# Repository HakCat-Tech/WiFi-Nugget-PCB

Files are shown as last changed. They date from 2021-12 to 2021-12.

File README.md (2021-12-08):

# WiFi Nugget PCB
This repository contains the PCB design files for the ESP8266 based WiFi Nugget.

### Change Log + Specs
**Beta-v1.0:**  
This design is a proof of concept for a slimmer, more easily manfacturable design based off surface mount components.   
- 0603 SMD components
- ESP12F based module
- SH1106 OLED Screen
- Minimal PCB art

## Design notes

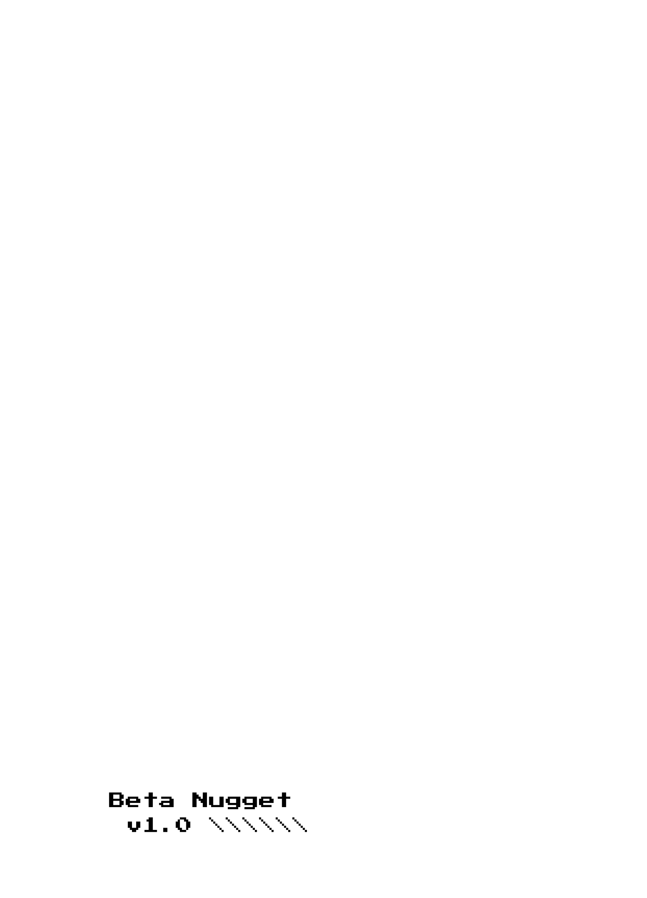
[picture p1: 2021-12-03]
v1.0-Beta-PCB-Art/.svg2shenzhen-cache/images/F.Mask_g1432.png

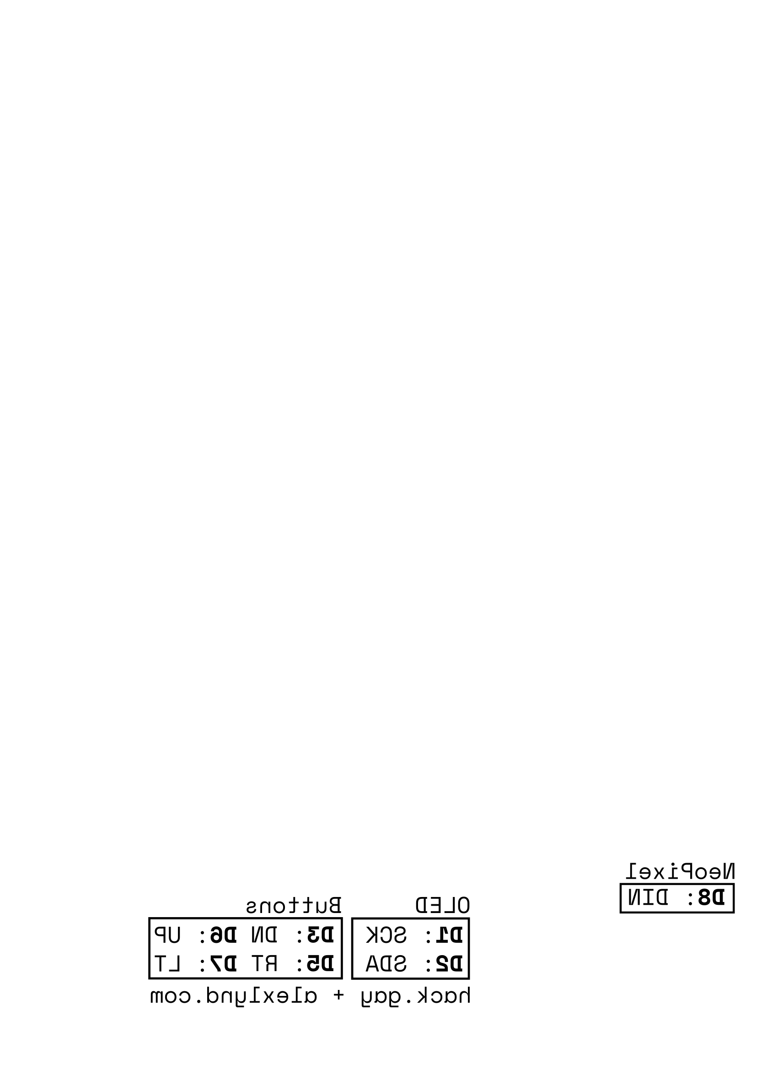
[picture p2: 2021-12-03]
v1.0-Beta-PCB-Art/.svg2shenzhen-cache/images/B.SilkS_g1428.png

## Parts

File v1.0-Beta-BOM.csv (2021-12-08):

Reference | Quantity | Value | Footprint | Datasheet
C4 C8 C10 C11 C12 C13 | 6 | 4.7μF | Capacitor_SMD:C_0603_1608Metric_Pad1.08x0.95mm_HandSolder | ~
C2 | 1 | 4.7 μF | Capacitor_SMD:C_0603_1608Metric_Pad1.08x0.95mm_HandSolder | ~
C1 C3 C5 C6 C7 C14 | 6 | 1 μF | Capacitor_SMD:C_0603_1608Metric_Pad1.08x0.95mm_HandSolder | ~
C9 | 1 | 1μF | Capacitor_SMD:C_0603_1608Metric_Pad1.08x0.95mm_HandSolder | ~
D1 | 1 | SS14 | LED_SMD:LED_0603_1608Metric_Pad1.05x0.95mm_HandSolder | ~
D2 | 1 | RED 0603 | LED_SMD:LED_0603_1608Metric_Pad1.05x0.95mm_HandSolder | ~
D3 | 1 | SS14 | Diode_SMD:D_SOD-123 | ~
D4 | 1 | WS2812B | LED_SMD:LED_WS2812B_PLCC4_5.0x5.0mm_P3.2mm | https://cdn-shop.adafruit.com/datasheets/WS2812B.pdf
J1 | 1 | Micro USB | Connector_USB:USB_Micro-B_Molex-105017-0001 | ~
J2 | 1 | JST PH 2.0 | Connector_JST:JST_PH_S2B-PH-SM4-TB_1x02-1MP_P2.00mm_Horizontal | ~
J3 | 1 | NeoPixel Breakout | Connector_JST:JST_SH_SM03B-SRSS-TB_1x03-1MP_P1.00mm_Horizontal | ~
Q1 | 1 | UMH3N | Package_TO_SOT_SMD:SOT-363_SC-70-6 | http://rohmfs.rohm.com/en/products/databook/datasheet/discrete/transistor/digital/emh3t2r-e.pdf
Q2 | 1 | DMG3415 | Package_TO_SOT_SMD:SOT-23 | ~
R1 R2 R3 R6 R8 R13 R16 R17 | 8 | 4.7K | Resistor_SMD:R_0603_1608Metric_Pad0.98x0.95mm_HandSolder | ~
R9 R10 R11 R12 R14 R15 | 6 | 10K | Resistor_SMD:R_0603_1608Metric_Pad0.98x0.95mm_HandSolder | ~
R4 | 1 | 560K | Resistor_SMD:R_0603_1608Metric_Pad0.98x0.95mm_HandSolder | ~
R5 | 1 | 100K | Resistor_SMD:R_0603_1608Metric_Pad0.98x0.95mm_HandSolder | ~
R7 | 1 | 27K | Resistor_SMD:R_0603_1608Metric_Pad0.98x0.95mm_HandSolder | ~
SW1 | 1 | SPDT | Button_Switch_SMD:SW_SPDT_PCM12 | https://www.digikey.com/en/products/detail/e-switch/EG1215AA/9559277
SW2 | 1 | UP | Button_Switch_SMD:SW_SPST_FSMSM | https://www.digikey.com/en/products/detail/c-k/PTS636-SM25F-SMTR-LFS/10071742
SW3 | 1 | Reset | Button_Switch_SMD:Panasonic_EVQPUM_EVQPUD | https://www.digikey.com/en/products/detail/w%C3%BCrth-elektronik/436331045822/5209092
SW4 | 1 | DOWN | Button_Switch_SMD:SW_SPST_FSMSM | https://www.digikey.com/en/products/detail/c-k/PTS636-SM25F-SMTR-LFS/10071742
SW5 | 1 | LEFT | Button_Switch_SMD:SW_SPST_FSMSM | https://www.digikey.com/en/products/detail/c-k/PTS636-SM25F-SMTR-LFS/10071742
SW6 | 1 | RIGHT | Button_Switch_SMD:SW_SPST_FSMSM | https://www.digikey.com/en/products/detail/c-k/PTS636-SM25F-SMTR-LFS/10071742
U1 | 1 | CP2102N-A01-GQFN24 | Package_DFN_QFN:QFN-24-1EP_4x4mm_P0.5mm_EP2.6x2.6mm | https://www.silabs.com/documents/public/data-sheets/cp2102n-datasheet.pdf
U2 | 1 | SH1106 | Display:OLED-128O064D | https://www.vishay.com/docs/37902/oled128o064dbpp3n00000.pdf
U3 | 1 | MCP73831-2-OT | Package_TO_SOT_SMD:SOT-23-5 | http://ww1.microchip.com/downloads/en/DeviceDoc/20001984g.pdf
U4 | 1 | ESP-12F | RF_Module:ESP-12E | http://wiki.ai-thinker.com/_media/esp8266/esp8266_series_modules_user_manual_v1.1.pdf
U5 | 1 | AP2112K-3.3 | Package_TO_SOT_SMD:SOT-23-5 | https://www.diodes.com/assets/Datasheets/AP2112.pdf

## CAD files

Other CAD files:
v1.0-Beta-PCB-Art/Board-Outline.FCStd
v1.0-Beta-PCB-Art/Board-Outline.dxf

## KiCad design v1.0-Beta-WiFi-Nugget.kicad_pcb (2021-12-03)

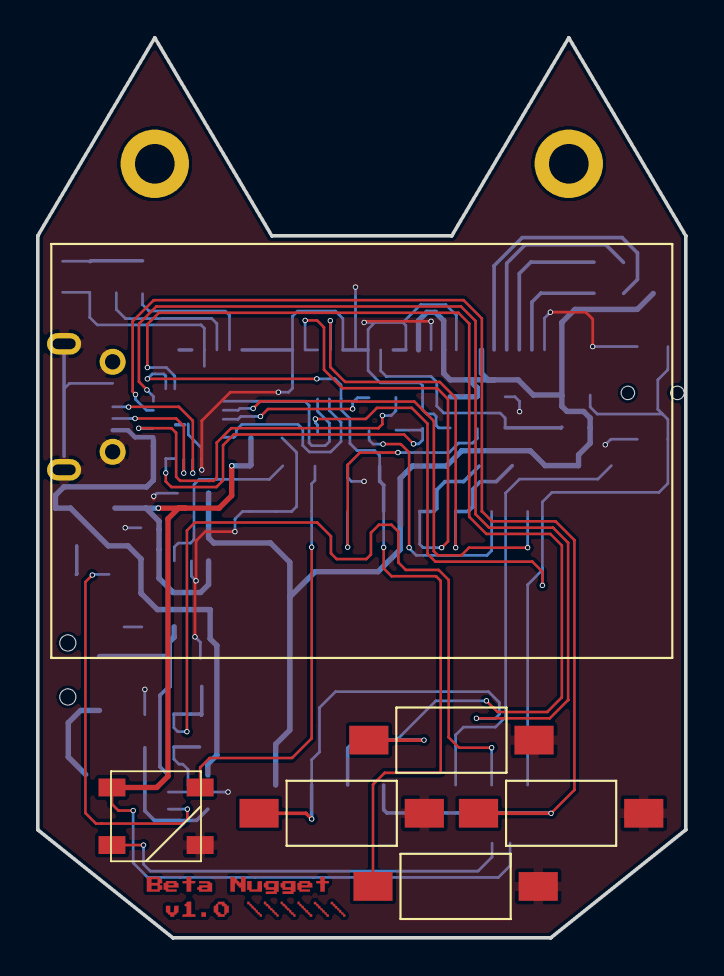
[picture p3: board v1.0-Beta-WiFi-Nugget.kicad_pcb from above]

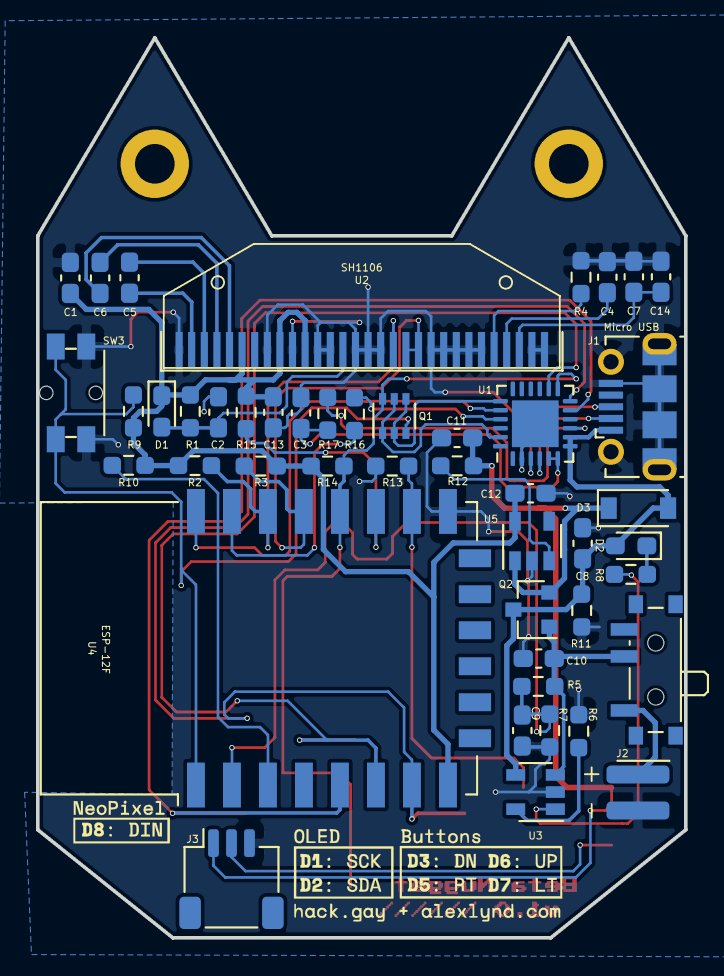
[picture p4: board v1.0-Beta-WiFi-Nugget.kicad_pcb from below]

Board: 2 copper layers, 36.0 x 50.0 mm, 52 parts (46 on the bottom side), 39 nets.

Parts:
C1, C3, C5, C6: 1 μF; C_0603_1608Metric_Pad1.08x0.95mm_HandSolder
C2: 10 μF; C_0603_1608Metric_Pad1.08x0.95mm_HandSolder
C4, C8, C10, C11, C12, C13: 4.7μF; C_0603_1608Metric_Pad1.08x0.95mm_HandSolder
C7, C14: C_Small; C_0603_1608Metric_Pad1.08x0.95mm_HandSolder
C9: 1μF; C_0603_1608Metric_Pad1.08x0.95mm_HandSolder
D1: SS14; LED_0603_1608Metric_Pad1.05x0.95mm_HandSolder
D2: RED; LED_0603_1608Metric_Pad1.05x0.95mm_HandSolder
D3: SS14; D_SOD-123
D4: WS2812B; LED_WS2812B_PLCC4_5.0x5.0mm_P3.2mm
J1: Micro USB; USB_Micro-B_Molex-105017-0001
J2: JST PH 2.0; JST_PH_S2B-PH-SM4-TB_1x02-1MP_P2.00mm_Horizontal
J3: JST_SH_SM03B-SRSS-TB_1x03-1MP_P1.00mm_Horizontal
Q1: UMH3N; SOT-363_SC-70-6
Q2: DMG3415; SOT-23
R1, R2, R3, R6, R13: 4.7K; R_0603_1608Metric_Pad0.98x0.95mm_HandSolder
R4: 560K; R_0603_1608Metric_Pad0.98x0.95mm_HandSolder
R5: 100K; R_0603_1608Metric_Pad0.98x0.95mm_HandSolder
R7: 27K; R_0603_1608Metric_Pad0.98x0.95mm_HandSolder
R8: 5K; R_0603_1608Metric_Pad0.98x0.95mm_HandSolder
R9, R10, R11, R12, R14, R15: 10K; R_0603_1608Metric_Pad0.98x0.95mm_HandSolder
R16: 1K; R_0603_1608Metric_Pad0.98x0.95mm_HandSolder
R17: R_Small_US; R_0603_1608Metric_Pad0.98x0.95mm_HandSolder
Ref**: Val**; Deluxe-Nugg-Board-Art
SW1: SPDT; SW_SPDT_PCM12
SW2: UP; SW_SPST_FSMSM
SW3: Reset; Panasonic_EVQPUM_EVQPUD
SW4: DOWN; SW_SPST_FSMSM
SW5: LEFT; SW_SPST_FSMSM
SW6: RIGHT; SW_SPST_FSMSM
U1: CP2102N-A01-GQFN24; QFN-24-1EP_4x4mm_P0.5mm_EP2.6x2.6mm
U2: SH1106; OLED-128O064D
U3: MCP73831-2-OT; SOT-23-5
U4: ESP-12F; ESP-12E
U5: AP2112K-3.3; SOT-23-5

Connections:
+3V3: C1.1, C12.1, C13.1, D1.1, R1.2, R2.1, R3.1, R9.1, R10.1, R14.1, R15.1, U2.6, U2.9, U2.11, U4.8, U5.5
+BATT: C10.1, Q2.1, R5.2, SW1.2, U3.3
A0: C9.2, R5.1, R7.2, U4.2
DOUT: D4.2, J3.2
DTR: Q1.1, Q1.5, U1.23
ESP_RST: Q1.3, R9.2, SW3.1, U4.1
GNDREF: C1.2, C2.2, C3.1, C4.2, C7.1, C8.2, C9.1, C10.2, C11.2, C12.2, C13.2, C14.1, D4.3, J1.5, J1.6, J2.2, J3.3, R4.2, R6.2, R7.1, R11.2, R13.2, SW2.2, SW3.2, SW4.2, SW5.2, SW6.2, U1.2, U1.25, U2.1, U2.8, U2.10, U2.12, U2.13, U2.15, U2.16, U2.17, U2.21, U2.22, U2.23, U2.24, U2.25, U2.29, U2.30, U3.2, U4.15, U5.2
GPIO0: Q1.6, R14.2, SW4.1, U1.13, U4.18
GPIO12: SW2.1, U1.14, U4.6
GPIO13: SW5.1, U1.12, U4.7
GPIO14: SW6.1, U1.11, U4.5
GPIO15: D4.4, R13.1, U4.16
unnamed: C3.2, R17.2, U1.5, U1.6
unnamed: C4.1, U2.27
unnamed: C5.1, U2.2
unnamed: C5.2, U2.3
unnamed: C6.1, U2.4
unnamed: C6.2, U2.5
unnamed: C7.2, C14.2, U2.28
unnamed: D2.1, R8.1
unnamed: J1.2, U1.4
unnamed: J1.3, U1.3
unnamed: J2.1, SW1.1
unnamed: R4.1, U2.26
unnamed: R6.1, U3.5
unnamed: R8.2, U3.1
unnamed: R10.2, U4.3
unnamed: R12.1, U5.3
unnamed: R15.2, U4.17
unnamed: R16.2, U4.21
unnamed: R17.1, U1.9
RES: C2.1, D1.2, R1.1, U2.14
RTS: Q1.2, Q1.4, U1.19
SCL: R2.2, U2.18, U4.20
SDA: R3.2, U2.19, U2.20, U4.19
TXD: U1.20, U4.22
USB_RX: R16.1, U1.21
VBUS: C8.1, D2.2, D3.2, J1.1, Q2.3, R11.1, U1.7, U1.8, U3.4
VMAX: C11.1, D3.1, D4.1, J3.1, Q2.2, R12.2, U5.1

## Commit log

2021-12-03 v1.0 beta PCB files
    [Nugget-Board-Outline.FCStd, Nugget-Board-Outline.dxf, v1.0-Beta-WiFi-Nugget.kicad_pcb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]
2021-12-03 v1.0 board file update
    [v1.0-Beta-WiFi-Nugget.kicad_pcb]
2021-12-08 v1.0 gerber + bom files
    [v1.0-Beta-WiFi-Nugget.csv, v1.0-Beta-WiFi-Nugget.kicad_pcb]
2021-12-08 update BOM + gerber file v1.0
    [v1.0-BOM-Beta-WiFi-Nugget.csv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]
2021-12-08 update naming convention + board files
    [BOM.csv, Board-Outline.FCStd, Board-Outline.dxf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]
2021-12-08 update file names
    [Board-Outline.FCStd, Board-Outline.dxf, v1.0-Beta-BOM.csv]
